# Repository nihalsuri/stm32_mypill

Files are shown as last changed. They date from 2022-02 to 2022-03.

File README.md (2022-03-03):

# stm32_mypill
Personal take on the STM32 line of pill devices 

* This project is made in KiCAD 6.0 and is a basic and simple breakout board for the STM32F103C8T6. 

* All the files required for manafacturing purposes are in the "manafacturing" folder which is a part of the **stm32myPill** directory. 

# Schematic


# PCB



# 3D View



# Final Product 



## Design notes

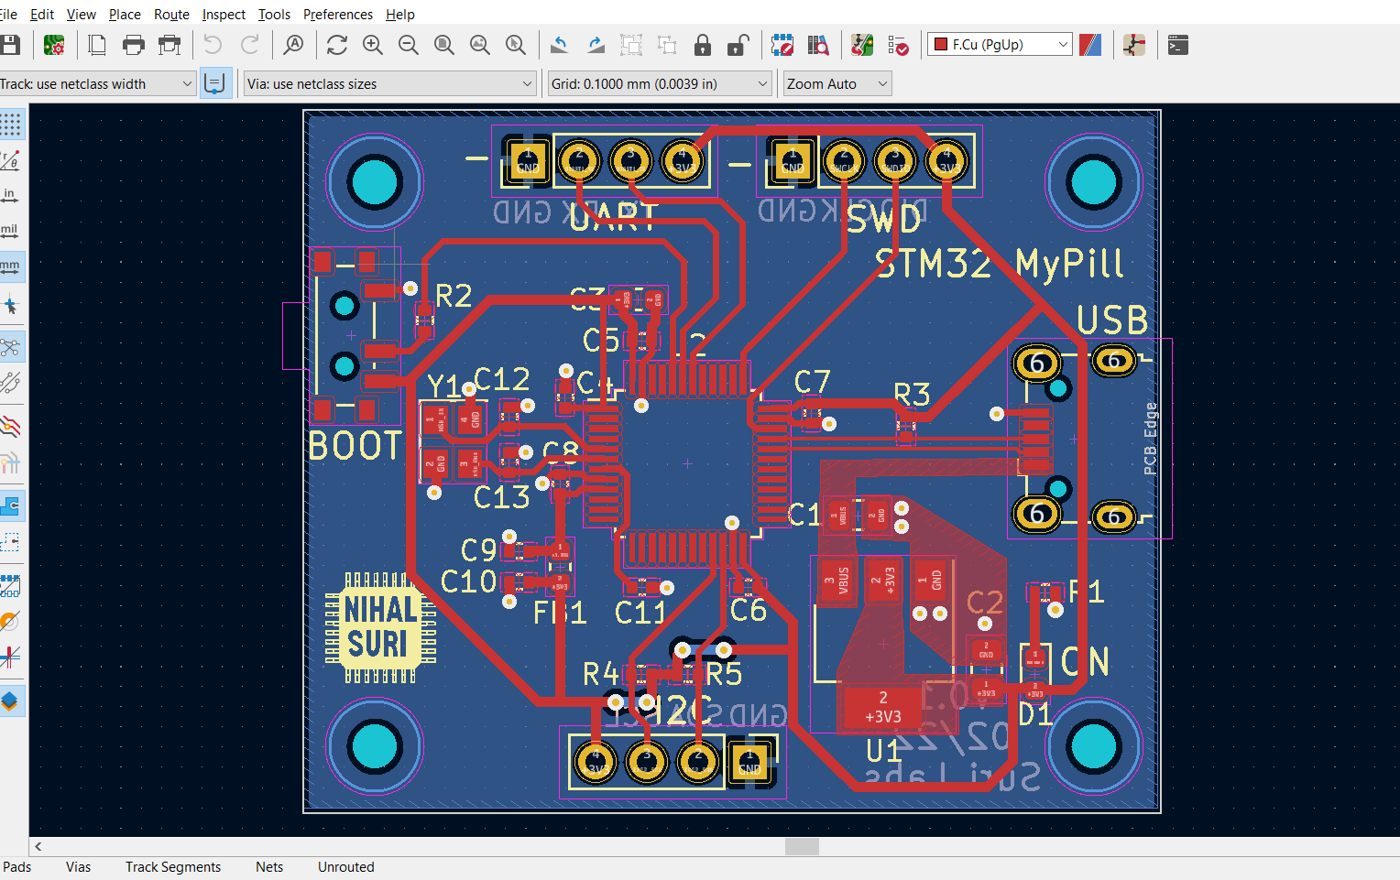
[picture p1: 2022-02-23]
stm32myPill/photos/pcb.PNG

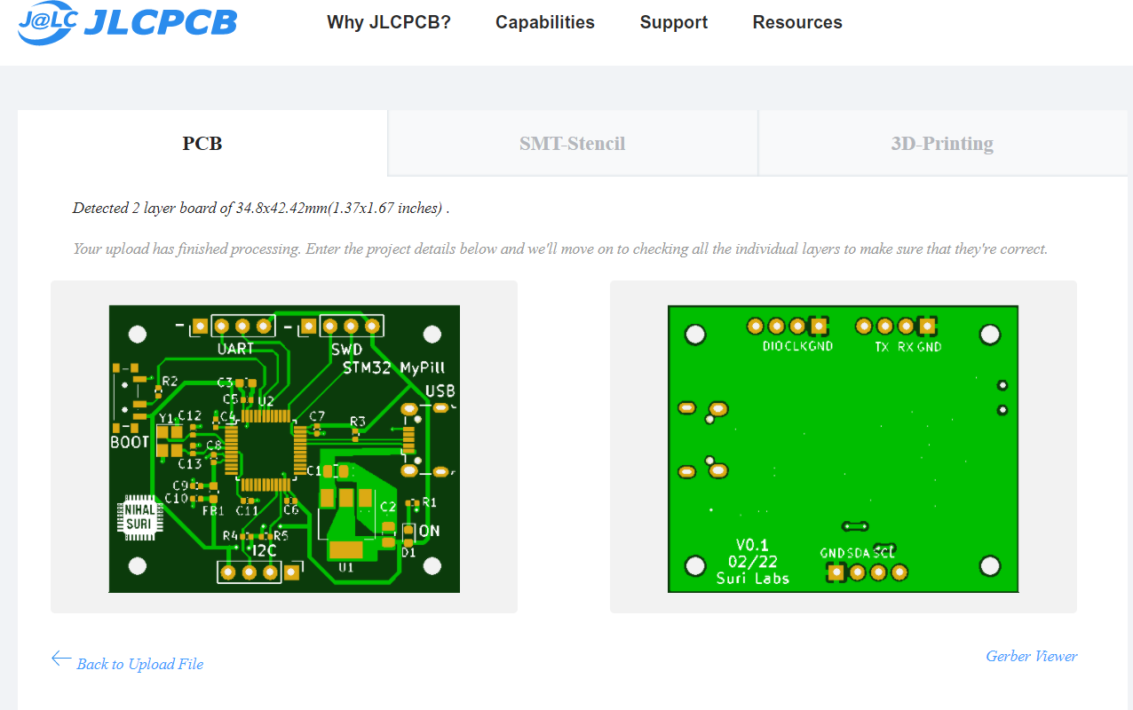
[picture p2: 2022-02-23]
stm32myPill/photos/jlc.PNG

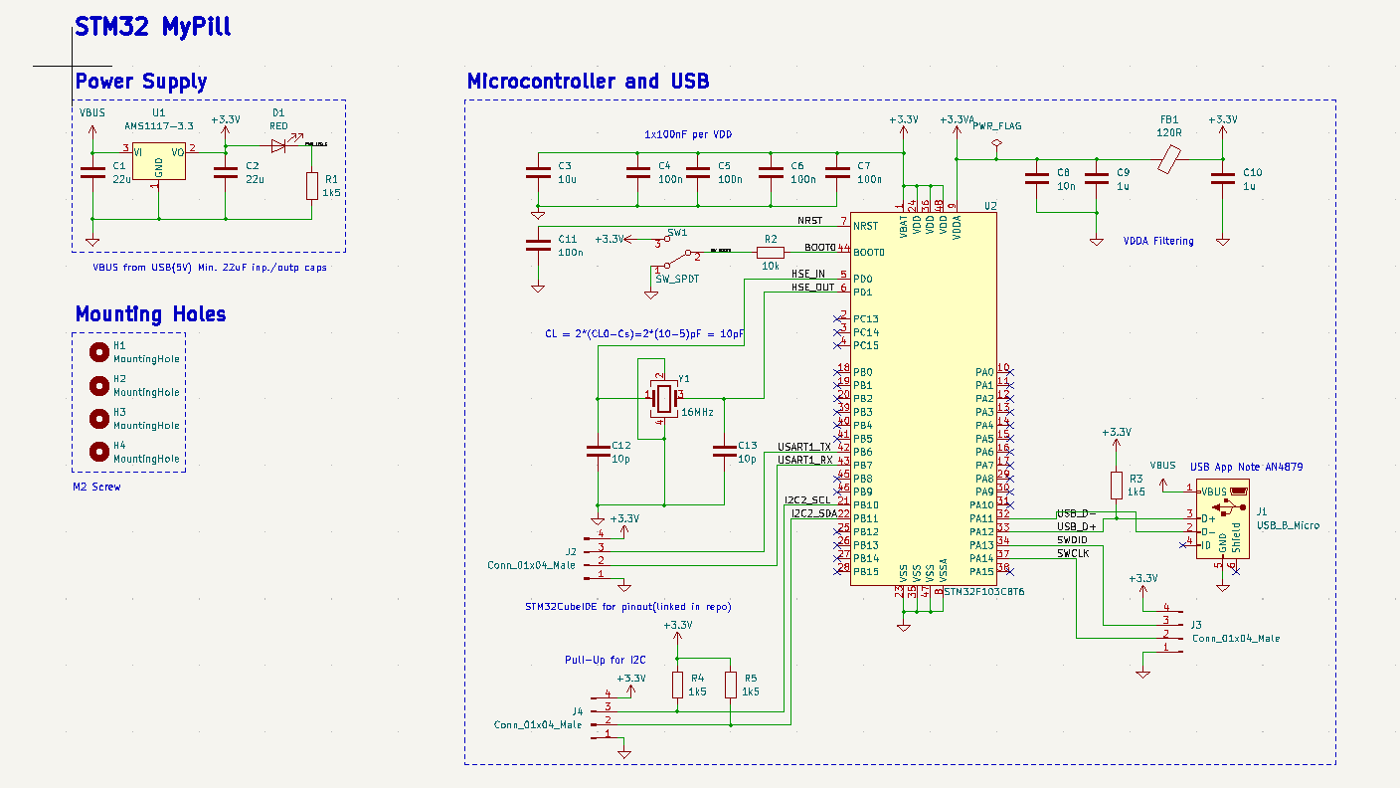
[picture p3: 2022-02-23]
stm32myPill/photos/sch.PNG

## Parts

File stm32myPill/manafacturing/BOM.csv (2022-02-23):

Ref | Qnty | Value | Cmp name | Footprint | Description | Vendor
C1, C2, | 2 | 22u | C | Capacitor_SMD:C_0805_2012Metric | Unpolarized capacitor
C3, | 1 | 10u | C | Capacitor_SMD:C_0603_1608Metric | Unpolarized capacitor
C4, C5, C6, C7, C11, | 5 | 100n | C | Capacitor_SMD:C_0402_1005Metric | Unpolarized capacitor
C8, | 1 | 10n | C | Capacitor_SMD:C_0402_1005Metric | Unpolarized capacitor
C9, C10, | 2 | 1u | C | Capacitor_SMD:C_0402_1005Metric | Unpolarized capacitor
C12, C13, | 2 | 10p | C | Capacitor_SMD:C_0402_1005Metric | Unpolarized capacitor
D1, | 1 | RED | LED | LED_SMD:LED_0603_1608Metric | Light emitting diode
FB1, | 1 | 120R | FerriteBead | Inductor_SMD:L_0603_1608Metric | Ferrite bead
J1, | 1 | USB_B_Micro | USB_B_Micro | Connector_USB:USB_Micro-B_Wuerth_629105150521 | USB Micro Type B connector
J2, J3, J4, | 3 | Conn_01x04_Male | Conn_01x04_Male | Connector_PinHeader_2.54mm:PinHeader_1x04_P2.54mm_Vertical | Generic connector, single row, 01x04, script generated (kicad-library-utils/schlib/autogen/connector/)
R1, R3, R4, R5, | 4 | 1k5 | R | Resistor_SMD:R_0402_1005Metric | Resistor
R2, | 1 | 10k | R | Resistor_SMD:R_0402_1005Metric | Resistor
SW1, | 1 | SW_SPDT | SW_SPDT | Button_Switch_SMD:SW_SPDT_PCM12 | Switch, single pole double throw
U1, | 1 | AMS1117-3.3 | AMS1117-3.3 | Package_TO_SOT_SMD:SOT-223-3_TabPin2 | 1A Low Dropout regulator, positive, 3.3V fixed output, SOT-223
U2, | 1 | STM32F103C8T6 | STM32F103C8Tx | Package_QFP:LQFP-48_7x7mm_P0.5mm | ARM Cortex-M3 MCU, 64KB flash, 20KB RAM, 72MHz, 2-3.6V, 37 GPIO, LQFP-48
Y1, | 1 | 16MHz | Crystal_GND24 | Crystal:Crystal_SMD_3225-4Pin_3.2x2.5mm | Four pin crystal, GND on pins 2 and 4

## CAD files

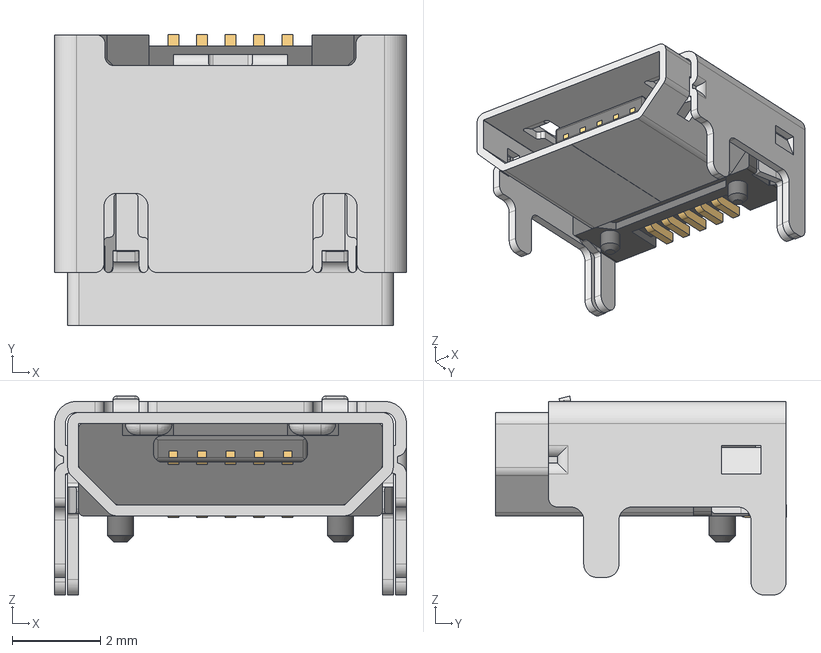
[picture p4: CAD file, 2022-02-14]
stm32myPill/629105150521 (rev1).stp
8.00 x 6.60 x 4.52 mm
629105150521_Pin1 x 4
629105150521_Housing
629105150521_Pin2
629105150521_Shielding
629105150521_Shielding2

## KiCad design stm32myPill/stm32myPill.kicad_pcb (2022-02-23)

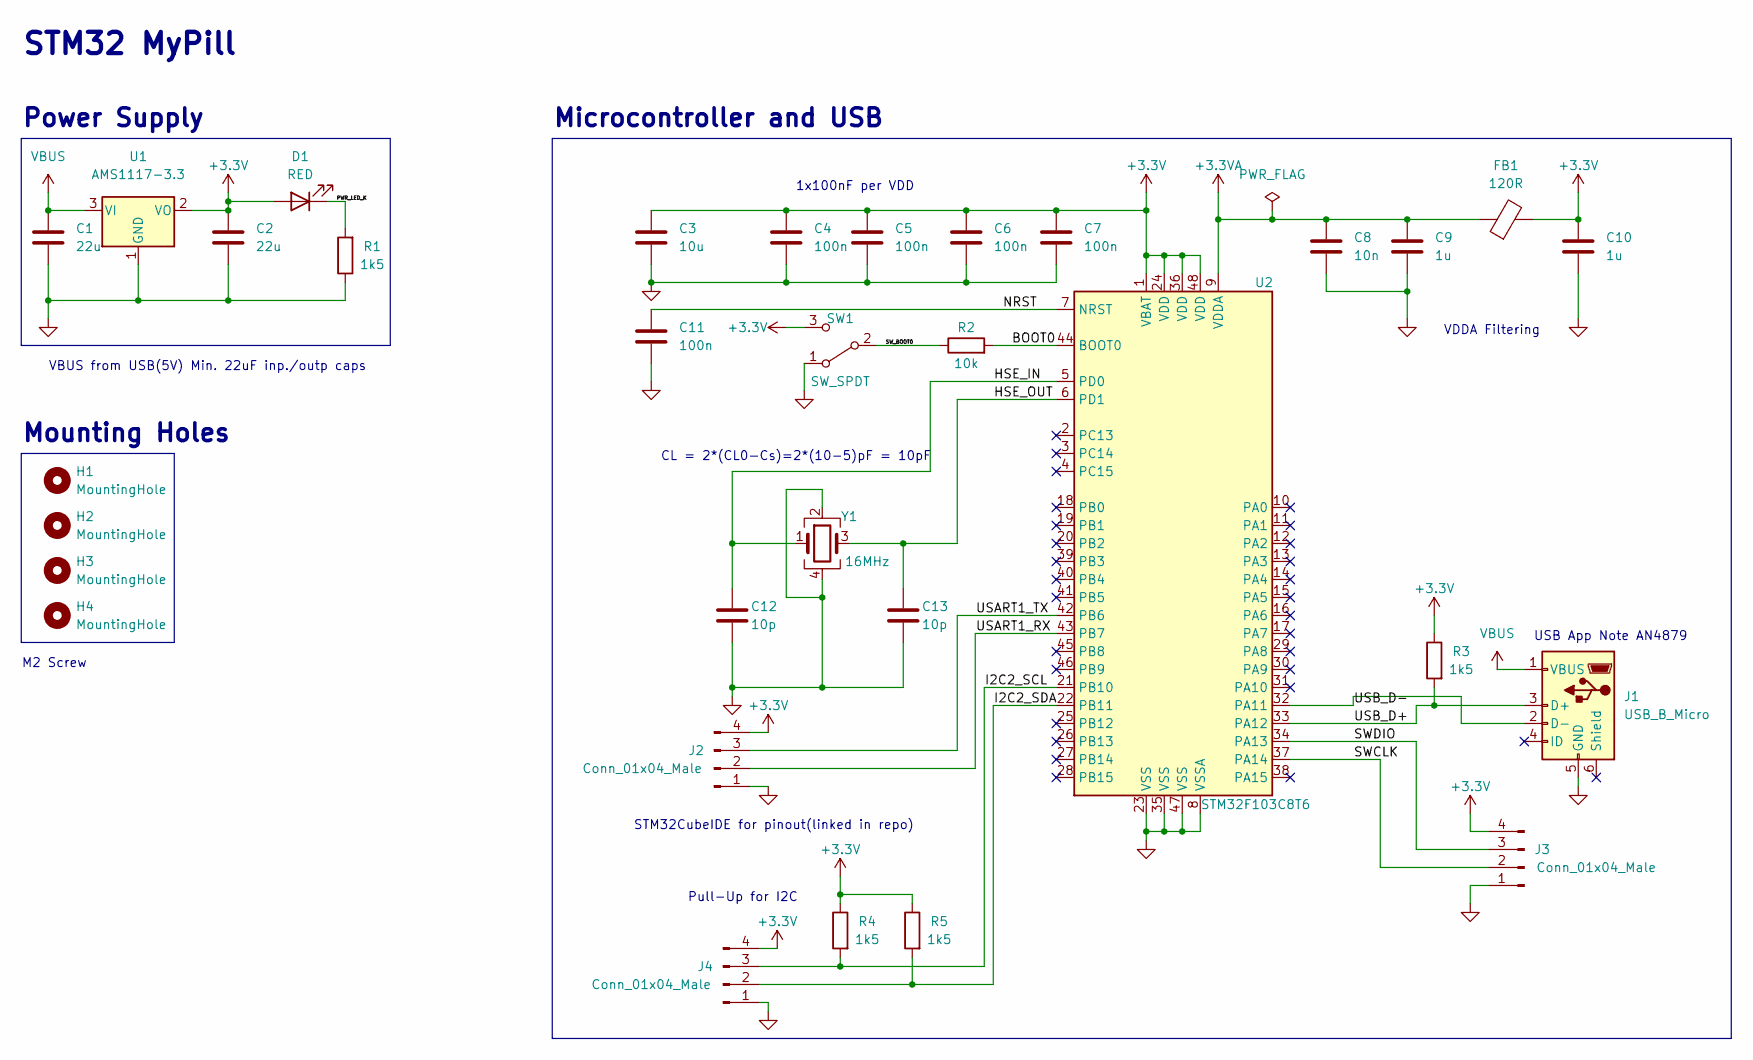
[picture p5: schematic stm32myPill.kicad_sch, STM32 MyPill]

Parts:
C1, C2: 22u; C_0805_2012Metric
C3: 10u; C_0603_1608Metric
C4, C5, C6, C7, C11: 100n; C_0402_1005Metric
C8: 10n; C_0402_1005Metric
C9, C10: 1u; C_0402_1005Metric
C12, C13: 10p; C_0402_1005Metric
D1: RED; LED_0603_1608Metric
FB1: 120R; L_0603_1608Metric
H1, H2, H3, H4: MountingHole; MountingHole_2.2mm_M2
J1: USB_B_Micro; USB_Micro-B_Wuerth_629105150521
J2, J3, J4: Conn_01x04_Male; PinHeader_1x04_P2.54mm_Vertical
R1, R3, R4, R5: 1k5; R_0402_1005Metric
R2: 10k; R_0402_1005Metric
SW1: SW_SPDT; SW_SPDT_PCM12
U1: AMS1117-3.3; SOT-223-3_TabPin2
U2: STM32F103C8T6; LQFP-48_7x7mm_P0.5mm
Y1: 16MHz; Crystal_SMD_3225-4Pin_3.2x2.5mm

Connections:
+3.3VA: C8.1, C9.1, FB1.1, U2.9 (VDDA)
+3V3: C2.1, C3.1, C4.1, C5.1, C6.1, C7.1, C10.1, D1.2 (A), FB1.2, J2.4, J3.4, J4.4, R3.1, R4.1, R5.1, SW1.3 (C), U1.2 (VO), U2.1 (VBAT), U2.24 (VDD), U2.36 (VDD), U2.48 (VDD)
/BOOT0: R2.2, U2.44 (BOOT0)
/HSE_IN: C12.1, U2.5 (PD0), Y1.1
/HSE_OUT: C13.1, U2.6 (PD1), Y1.3
/I2C2_SCL: J4.3, R4.2, U2.21 (PB10)
/I2C2_SDA: J4.2, R5.2, U2.22 (PB11)
/NRST: C11.1, U2.7 (NRST)
/PWR_LED_K: D1.1 (K), R1.2
/SWCLK: J3.2, U2.37 (PA14)
/SWDIO: J3.3, U2.34 (PA13)
/SW_BOOT0: R2.1, SW1.2 (B)
/USART1_RX: J2.2, U2.43 (PB7)
/USART1_TX: J2.3, U2.42 (PB6)
/USB_D+: J1.3 (D+), R3.2, U2.33 (PA12)
/USB_D-: J1.2 (D-), U2.32 (PA11)
GND: C1.2, C2.2, C3.2, C4.2, C5.2, C6.2, C7.2, C8.2, C9.2, C10.2, C11.2, C12.2, C13.2, J1.5 (GND), J2.1, J3.1, J4.1, R1.1, SW1.1 (A), U1.1 (GND), U2.8 (VSSA), U2.23 (VSS), U2.35 (VSS), U2.47 (VSS), Y1.2, Y1.4
VBUS: C1.1, J1.1 (VBUS), U1.3 (VI)

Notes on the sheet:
STM32 MyPill
Pull-Up for I2C
Mounting Holes
CL = 2*(CL0-Cs)=2*(10-5)pF = 10pF
VDDA Filtering
Power Supply
USB App Note AN4879
1x100nF per VDD
STM32CubeIDE for pinout(linked in repo)
M2 Screw
Microcontroller and USB
VBUS from USB(5V) Min. 22uF inp./outp caps

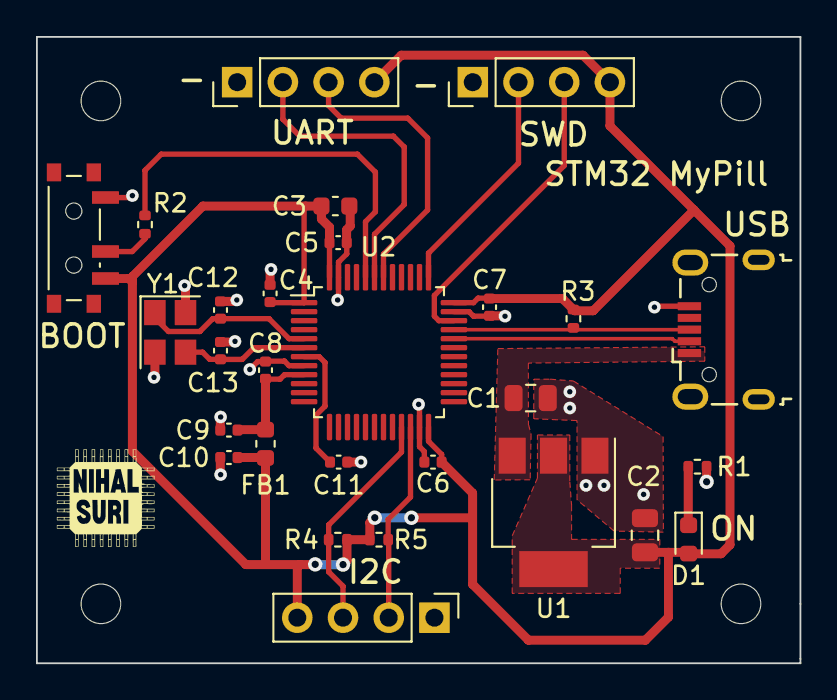
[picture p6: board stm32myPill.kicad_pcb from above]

Board: 2 copper layers, 42.4 x 34.8 mm, 32 parts (0 on the bottom side), 18 nets.

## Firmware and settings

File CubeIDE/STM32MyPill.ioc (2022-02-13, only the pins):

Mcu.UserName=STM32F103C8Tx
PA1.Signal=S_TIM2_CH2
PA11.Signal=USB_DM
PA12.Signal=USB_DP
PA13.Signal=SYS_JTMS-SWDIO
PA14.Signal=SYS_JTCK-SWCLK
PA3.Signal=ADCx_IN3
PB10.Signal=I2C2_SCL
PB11.Signal=I2C2_SDA
PB6.Signal=USART1_TX
PB7.Signal=USART1_RX
PD0-OSC_IN.Signal=RCC_OSC_IN
PD1-OSC_OUT.Signal=RCC_OSC_OUT

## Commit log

2022-02-11 added CubeIDE and finished MCU schematic
    [stm32myPill.kicad_sch]
2022-02-13 completed sch and added footprints
    [stm32myPill.kicad_sch]
2022-02-14 finished layout added mounting holes
    [stm32myPill.kicad_pcb, stm32myPill.kicad_sch]
2022-02-14 3D Model for USB
    [629105150521 (rev1).stp]
2022-02-22 finished pcb
    [stm32myPill.kicad_pcb]
2022-02-23 added manafacturing files
    [BOM.csv, position_file.csv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]
2022-02-23 added photos
    [stm32myPill.kicad_pcb]
